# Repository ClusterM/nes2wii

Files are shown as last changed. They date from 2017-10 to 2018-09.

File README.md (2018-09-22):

# NES2Wii

NES2Wii - adapter for NES/SNES/N64/SMD/DualShock gamepad to NES Mini, SNES Mini or Wii remote

Features:

* You can play Wii virtual console games using original NES/SNES/N64/SMD/DualShock gamepad!
* You can use original NES/SNES/N64/SMD/DualShock controllers with NES Mini or SNES Mini
* You can connect Wiimote to PC via bluetooth and use original NES/SNES/N64/SMD/DualShock controllers with emulators

## Schematics

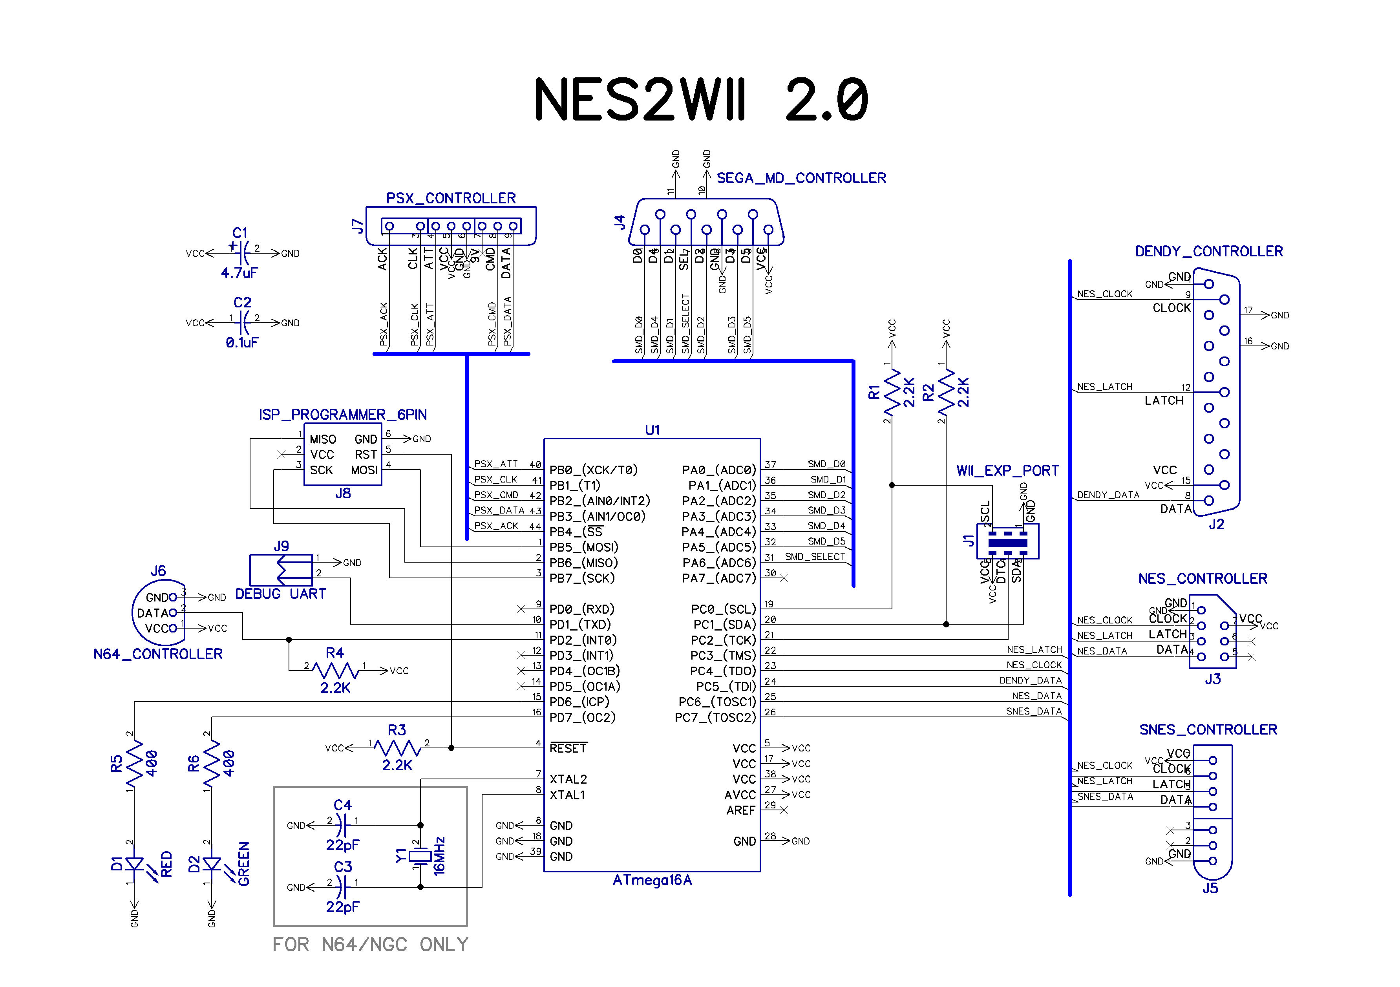
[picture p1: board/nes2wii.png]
Schematics


Just ATMEGA16A (or any other low-power ATMEGA). You need 16MHz crystal for N64. 8MHz internal oscillator is fine if you don't need N64.

## Fuses (for ATMEGA16 with crystal)

* Low fuse: 0xFF
* High fuse: 0xD9

## How to use with PC

Just install HID Wiimote driver by Julian Lohr: [http://julianloehr.de/educational-work/hid-wiimote/](http://julianloehr.de/educational-work/hid-wiimote/ "http://julianloehr.de/educational-work/hid-wiimote/")

## Tested on

* ATMEGA16A, 16MHz crystal
* ATMEGA8A, 8MHz (without N64 support)
* NES, SNES, N64, SMD and DualShock controllers

## Modes

There are three modes for NES/SNES/SMD controllers:
* Mode #1 - d-pad works as left analog stick and d-pad on classic controller at the same time
* Mode #2 - d-pad works as left analog stick only
* Mode #3 - d-pad works as d-pad only

You can hold Start+A+B for a few seconds to change mode. Red led will blink 1/2/3 times indicating new mode.

## Notes

* You can select pins and required controllers in *defines.h*.
* *Detect* (*DTCT*) wire is optional but recommended to prevent some glitches. If not used it must be connected directly to VCC.

## Author/contacts

**Alexey 'Cluster' Avdyukhin**

clusterrr@clusterrr.com

[https://github.com/ClusterM](https://github.com/ClusterM "https://github.com/ClusterM")

[http://clusterrr.com](http://clusterrr.com "http://clusterrr.com")

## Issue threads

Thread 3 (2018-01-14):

first retry fail :(

khrys63, 2018-01-14:
Hi

I test with ATMEGA16A, without 16MHz crystal.
I use nes2wii.hex as is, not recompiled.

I use USB ASP Device and WinAVR  for programming ATMEGA16A, and it's ok.

I use pin 1, 2, 3 and 4 for programming.
I map 30 to 37 for Genesis controler
I map 19, 20 and 21for Wii controler (19 & 20 with 2.2k resist to the VCC)

I put a 4.7µF

It didnt work :(

I dont put LED n 15 and 16, is it the problem?
I dont put Crystal, is it the problem?

During test, i've 2.9V between VCC and GND on the ATMEGA16A  (pin 38 and 39)

khrys63, 2018-01-14:
I use an ATMEGA16A TQFP
and my command line to programming was : avrdude -p atmega16 -P usb -c usbasp -U flash:w:nes2wii.hex
(without Fuse)

khrys63, 2018-01-20:
New command line :
avrdude -V -p atmega16 -P usb -c usbasp -U flash:w:nes2wii.hex -U lfuse:w:0xFF:m -U hfuse:w:0xD9:m

I add LED on 15 and 16 pin.

same problem :(

ClusterM, 2018-03-10:
Fuses FF D9 are for external crystal. You can change fuses to use internal oscillator, but it can work on 8MHz only.

khrys63, 2018-03-10:
I use http://www.engbedded.com/fusecalc/ to find good fuse for internal 8MHz : C8-D9.

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

It didnt work. LED didn't flash, and gamepad is non functionnal :(

ClusterM, 2018-04-19:
Do you changed working frequency in defines.h?

khrys63, 2018-04-19:
No :(

khrys63, 2018-04-19:
I use hex file as is.
And since my last avrdude, my atmega seems be a brick. I Can reuse or :(

It a very good project, i need it for my retro gaming session but i dont have the knowledge on atmega to finish it

khrys63, 2018-04-19:
I can't reuse it. (Sorry for my french Android autocompletion)

Closed 2018-09-22.

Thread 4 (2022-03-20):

I can't generate .hex file

davidxgames, 2022-03-20:
hello i want to put together your project it seems great to me but i am very newbie can you provide me a hex for atmega8a-pu, atmega16a or can i use an arduino nano with atemega328p?
I ask a lot, but I only know a little about electronics. I will program with usbtiny and avrdudess.

hope you can help me.

ClusterM, 2023-08-02:
Oops, i noticed this issue only now. Do you still need it? :)

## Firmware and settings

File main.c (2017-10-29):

#include "nes2wii.h"
#include "defines.h"
#include <util/delay.h>
#include <avr/eeprom.h>
#include <avr/wdt.h>
#include <inttypes.h>
#include "wiimote.h"
#include "gamepads.h"

// classic controller id
const unsigned char classic_controller_id[6] = {0x00, 0x00, 0xA4, 0x20, 0x01, 0x01};

volatile int8_t jx = 0, jy = 0, rx = 0, ry = 0;
volatile uint8_t tl = 0, tr = 0;
volatile uint8_t left = 0, right = 0, up = 0, down = 0, a = 0, b = 0, x = 0, y = 0, 
				select = 0, start = 0, home = 0, l = 0, r = 0, zl = 0, zr = 0;
volatile uint8_t connected = 0;
volatile uint8_t dpad_mode = DPAD_MODE_BOTH;

// calibration data
const unsigned char cal_data[32] = {
	0x00, 0x00, 0x00, 0x00,
	0x00, 0x00, 0x00, 0x00,
	0x00, 0x00, 0x00, 0x00,
	0x00, 0x00, 0x00, 0x00,
	0x00, 0x00, 0x00, 0x00,
	0x00, 0x00, 0x00, 0x00,
	0x00, 0x00, 0x00, 0x00,
	0x00, 0x00, 0x00, 0x00
};

void wiimote_query()
{
	wdt_reset();
	if (connected < 2)
	{
		connected = 2;
		RED_ON;
	}
	unsigned char but_dat[8]; // struct containing button data
	if (twi_reg[0xFE] == 1) // data format
	{
		but_dat[0] = 0b00000000; // RX<4:3>	LX<5:0>
		but_dat[1] = 0b00000000; // RX<2:1>	LY<5:0>
		but_dat[2] = 0b00000000; // RX<0>	LT<4:3>	RY<4:0>
		but_dat[3] = 0b00000000; // LT<2:0>	RT<4:0>
		but_dat[4] = 0b11111111; // BDR	BDD	BLT	B-	BH	B+	BRT	 1
		but_dat[5] = 0b11111111; // BZL	BB	BY	BA	BX	BZR	BDL	BDU
		but_dat[6] = 0;
		but_dat[7] = 0;
		
		but_dat[0] |= (jx / 4 + 0x20) & 0x3F;
		but_dat[1] |= (jy / -4 + 0x20) & 0x3F;
		but_dat[0] |= ((rx / 8 + 0x10) & 0x18) << 3;
		but_dat[1] |= ((rx / 8 + 0x10) & 0x06) << 5;
		but_dat[2] |= ((rx / 8 + 0x10) & 0x01) << 7;
		but_dat[2] |= (ry / -8 + 0x10) & 0x1F;
		but_dat[2] |= ((tl / 8) & 0x18) << 2;
		but_dat[3] |= ((tl / 8) & 0x07) << 5;
		but_dat[3] |= (tr / 8) & 0x1F;

		if (right) but_dat[4] &= ~(1<<7);
		if (down) but_dat[4] &= ~(1<<6);
		if (l) but_dat[4] &= ~(1<<5);
		if (select) but_dat[4] &= ~(1<<4);
		if (home) but_dat[4] &= ~(1<<3);
		if (start) but_dat[4] &= ~(1<<2);
		if (r) but_dat[4] &= ~(1<<1);
		
		if (zl) but_dat[5] &= ~(1<<7);
		if (b) but_dat[5] &= ~(1<<6);
		if (y) but_dat[5] &= ~(1<<5);
		if (a) but_dat[5] &= ~(1<<4);
		if (x) but_dat[5] &= ~(1<<3);
		if (zr) but_dat[5] &= ~(1<<2);
		if (left) but_dat[5] &= ~(1<<1);
		if (up) but_dat[5] &= ~(1<<0);
		
		but_dat[6] = 0;
		but_dat[7] = 0;
		
		if (((but_dat[4] & 0xFE) == 0xFE) && (but_dat[5] == 0xFF) && 
			(ABS(jx) < DEAD_ZONE) && (ABS(jy) < DEAD_ZONE) &&
			(ABS(rx) < DEAD_ZONE) && (ABS(ry) < DEAD_ZONE))
			GREEN_OFF;
		else
			GREEN_ON;
		
		wm_newaction(but_dat);
	} 
	else if (twi_reg[0xFE] == 3) // data format
	{
		but_dat[0] = jx + 0x80;
		but_dat[1] = rx + 0x80;
		but_dat[2] = 0x7fl - jy;
		but_dat[3] = 0x7fl - ry;
		but_dat[4] = tl;
		but_dat[5] = tr;
			
		but_dat[6] = 0b11111111; // BDR	BDD	BLT	B-	BH	B+	BRT	 1
		but_dat[7] = 0b11111111; // BZL	BB	BY	BA	BX	BZR	BDL	BDU
			
		if (right) but_dat[6] &= ~(1<<7);
		if (down) but_dat[6] &= ~(1<<6);
		if (l) but_dat[6] &= ~(1<<5);
		if (select) but_dat[6] &= ~(1<<4);
		if (home) but_dat[6] &= ~(1<<3);
		if (start) but_dat[6] &= ~(1<<2);
		if (r) but_dat[6] &= ~(1<<1);

		if (zl) but_dat[7] &= ~(1<<7);
		if (b) but_dat[7] &= ~(1<<6);
		if (y) but_dat[7] &= ~(1<<5);
		if (a) but_dat[7] &= ~(1<<4);
		if (x) but_dat[7] &= ~(1<<3);
		if (zr) but_dat[7] &= ~(1<<2);
		if (left) but_dat[7] &= ~(1<<1);
		if (up) but_dat[7] &= ~(1<<0);

		if (((but_dat[6] & 0xFE) == 0xFE) && (but_dat[7] == 0xFF) &&
			(ABS(jx) < DEAD_ZONE) && (ABS(jy) < DEAD_ZONE) &&
			(ABS(rx) < DEAD_ZONE) && (ABS(ry) < DEAD_ZONE))
			GREEN_OFF;
		else
			GREEN_ON;

		wm_newaction(but_dat);
	} 
}

int main()
{
	RED_OFF;
	GREEN_OFF;
	RED_LED_PORT_DDR |= (1<<RED_LED_PIN); // Red led, output
	GREEN_LED_PORT_DDR |= (1<<GREEN_LED_PIN); // Red led, output
	gamepads_init();
	dpad_mode = eeprom_read_byte((void*)0); // current mode
	if (dpad_mode > 2) dpad_mode = DPAD_MODE_BOTH;

	wm_init((void*)classic_controller_id, (void*)cal_data, wiimote_query);
	connected = 1;
	wdt_enable(WDTO_2S);

	while(1)
	{
		if (connected == 2)
		{
			connected = 3;
		}

		gamepads_query();

		a = nes1.a || nes2.a || nes3.a || snes1.a || smd1.c || n64_1.a || dualshock1.circle;
		b = nes1.b || nes2.b || nes3.b || snes1.b || smd1.b || n64_1.b || dualshock1.cross;
		x = snes1.x || smd1.y || dualshock1.triangle;
		y = snes1.y || smd1.a || dualshock1.square;
		l = snes1.l || smd1.x || n64_1.l || dualshock1.l1;
		r = snes1.r || smd1.z || n64_1.r || dualshock1.r1;
		select = nes1.select || nes2.select || nes3.select || snes1.select || smd1.mode || dualshock1.select;
		start = nes1.start || nes2.start || nes3.start || snes1.start || smd1.start || n64_1.start || dualshock1.start;
		zl = n64_1.z || dualshock1.l2;
		zr = dualshock1.r2;

		uint8_t tmp_up = n64_1.up || dualshock1.up;
		uint8_t tmp_down = n64_1.down || dualshock1.down;
		uint8_t tmp_left = n64_1.left || dualshock1.left;
		uint8_t tmp_right = n64_1.right || dualshock1.right;
		if (dpad_mode == DPAD_MODE_BOTH || dpad_mode == DPAD_MODE_DPAD)
		{
			tmp_up |= nes1.up || nes2.up || nes3.up || snes1.up || smd1.up;
			tmp_down |= nes1.down || nes2.down || nes3.down || snes1.down || smd1.down;
			tmp_left |= nes1.left || nes2.left || nes3.left || snes1.left || smd1.left;
			tmp_right |= nes1.right || nes2.right || nes3.right || snes1.right || smd1.right;
		}
		up = tmp_up;
		down = tmp_down;
		left = tmp_left;
		right = tmp_right;

		int temp_jx = 0;
		int temp_jy = 0;
		int temp_rx = 0;
		int temp_ry = 0;
		if (dpad_mode == DPAD_MODE_BOTH || dpad_mode == DPAD_MODE_STICK)
		{
			if (nes1.up || nes2.up || nes3.up || snes1.up || smd1.up)
				temp_jy = -127;
			if (nes1.down || nes2.down || nes3.down || snes1.down || smd1.down)
				temp_jy = 127;
			if (nes1.left || nes2.left || nes3.left || snes1.left || smd1.left)
				temp_jx = -127;
			if (nes1.right || nes2.right || nes3.right || snes1.right || smd1.right)
				temp_jx = 127;
		}
		temp_jx = ABSMAX(temp_jx, n64_1.x * 80 / 30);
		temp_jy = ABSMAX(temp_jy, n64_1.y * 80 / 30);
		temp_rx = ABSMAX(temp_rx, n64_1.c_left*-127 + n64_1.c_right*127);
		temp_ry = ABSMAX(temp_ry, n64_1.c_up*-127 + n64_1.c_down*127);
		temp_jx = ABSMAX(temp_jx, dualshock1.lx);
		temp_jy = ABSMAX(temp_jy, dualshock1.ly);
		temp_rx = ABSMAX(temp_rx, dualshock1.rx);
		temp_ry = ABSMAX(temp_ry, dualshock1.ry);
		if (temp_jx > 127) temp_jx = 127;
		if (temp_jx < -127) temp_jx = -127;
		if (temp_jy > 127) temp_jy = 127;
		if (temp_jy < -127) temp_jy = -127;
		if (temp_rx > 127) temp_rx = 127;
		if (temp_rx < -127) temp_rx = -127;
		if (temp_ry > 127) temp_ry = 127;
		if (temp_ry < -127) temp_ry = -127;

		jx = temp_jx;
		jy = temp_jy;
		rx = temp_rx;
		ry = temp_ry;
		
		_delay_ms(1);

		// Need to switch mode? Hold Start+A+B for a second
		static uint16_t time = 0;
		if (start && a && b)
		{
			time++;
			if (time >= 500)
			{
				dpad_mode = (dpad_mode+1) % 3;
				eeprom_write_byte((void*)0, dpad_mode);
				RED_OFF;
				_delay_ms(1000);
				uint8_t i;
				for (i = 0; i <= dpad_mode; i++)
				{
					RED_ON;
					_delay_ms(200);
					RED_OFF;
					_delay_ms(200);
				}
				wdt_enable(WDTO_500MS);
				cli();
				while(1); // restart
			}
		} else time = 0;
	}
	return 0;
}

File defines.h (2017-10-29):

#ifndef _DEFINES_H_
#define _DEFINES_H_

#define F_CPU 16000000L
#define UART_BAUD 9600UL

#define TWI_PORT C
#define TWI_SCL_PIN 0
#define TWI_SDA_PIN 1

#define DETECT_PORT C
#define DETECT_PIN 2

#define NES_SNES_PORT C
#define NES_SNES_LATCH_PIN 3
#define NES_SNES_CLOCK_PIN 4
#define NES1_DATA_PIN 5
#define NES2_DATA_PIN 6
#define SNES1_DATA_PIN 7
//#define SNES2_DATA_PIN

#define SMD_SELECT_PORT A
#define SMD_SELECT_PIN 6
#define SMD1_DATA_PORT A
//#define SMD2_DATA_PORT A
#define SMD1_DATA_PIN0 0
#define SMD1_DATA_PIN1 1
#define SMD1_DATA_PIN2 2
#define SMD1_DATA_PIN3 3
#define SMD1_DATA_PIN4 4
#define SMD1_DATA_PIN5 5

#define SMD_USE_DENDY9_PIN

#define DUALSHOCK_PORT B
#define DUALSHOCK1_ATT_PIN 0
//#define DUALSHOSK2_ATT_PIN 0
#define DUALSHOCK_CLOCK_PIN 1
#define DUALSHOCK_CMD_PIN 2
#define DUALSHOCK_DATA_PIN 3

#define N64_PORT D
#define N64_1_DATA_PIN 2
//#define N64_2_DATA_PIN 2

#define RED_LED_PORT D
#define RED_LED_PIN 6
#define GREEN_LED_PORT D
#define GREEN_LED_PIN 7

#define DEAD_ZONE 32

#endif

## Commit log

2014-01-16 SNES fix (not tested)
    [main.c]
2014-01-16 Schematics and readme
    [nes2wii.sch]
2014-01-19 New schematics
    [nes2wii.sch]
2014-01-23 SMD 6 button mode fixed
    [main.c]
2014-01-24 Fuses in readme
2014-01-24 Leds support
2014-01-24 Leds support, code optimizations
2014-01-24 New schematics (leds)
    [nes2wii.sch]
2014-01-24 Sample board layout
2014-01-24 SMD button config mismatch fix
    [main.c]
2014-01-24 Board layout update
2014-01-27 Version with analog+d-pad emulation on NES/SNES/SMD controllers (instead of analog only emulation). Need some button to switch modes maybe?
2014-01-28 N64-data moved to pin D7
2014-01-29 SMD time saving & init fixes
    [main.c]
2014-01-29 Schematics and readme update for dualshock support
    [nes2wii.sch]
2015-05-25 watchdog, support for connection detect pin
2015-05-25 faster led blinking
2015-05-25 compatibility fixes, timings optimization
    [main.c]
2015-05-26 Detect pin, schematics for detect pin, updated readme
2017-10-29 New version
    [BoardOutline.gbr, Bottom.gbr, BottomMask.gbr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]
2018-09-22 Fix for 9-pin Dendy controller
    [gamepads.c]
